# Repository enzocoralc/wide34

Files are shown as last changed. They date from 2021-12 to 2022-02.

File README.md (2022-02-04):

# wide34

⚠️ If you've used the gerbers to fab before 2022/2/4 you'll need to bodge wire the middle TRRS pin (which was connected to P15) to P1 and the inner bottom key side pin (which was connected to P1) to P15.

split 34 keys with 21mm X pitch and chopped chocs for less vertical movement. 
It's promicro compatible and supports only chocs.
Designed in ergogen. You can use this wonderful tool [here](https://ergogen.xyz/). Disclaimer: the ergogen file here does not output the same edgecuts as the final pcb.

Left side

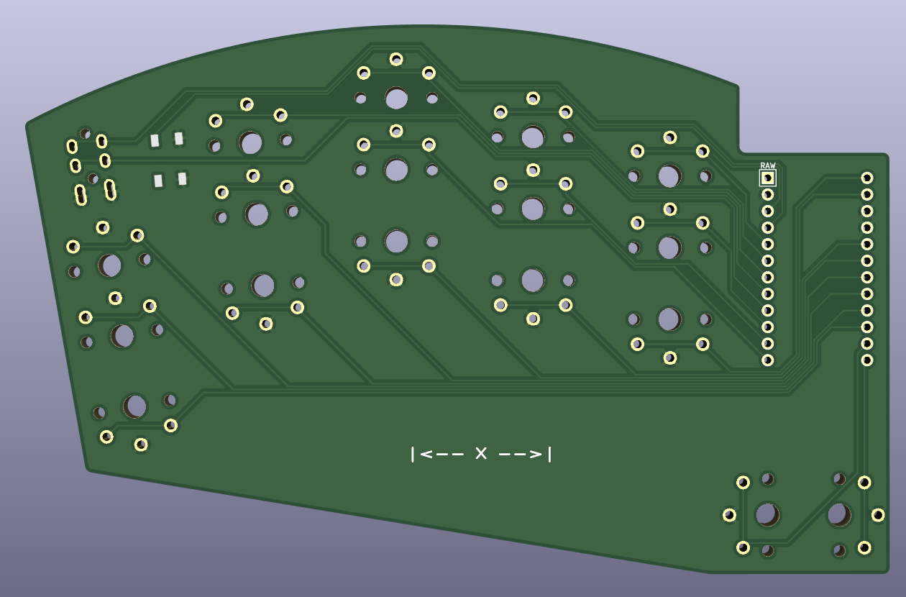
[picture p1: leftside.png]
 
 
 Right side
 
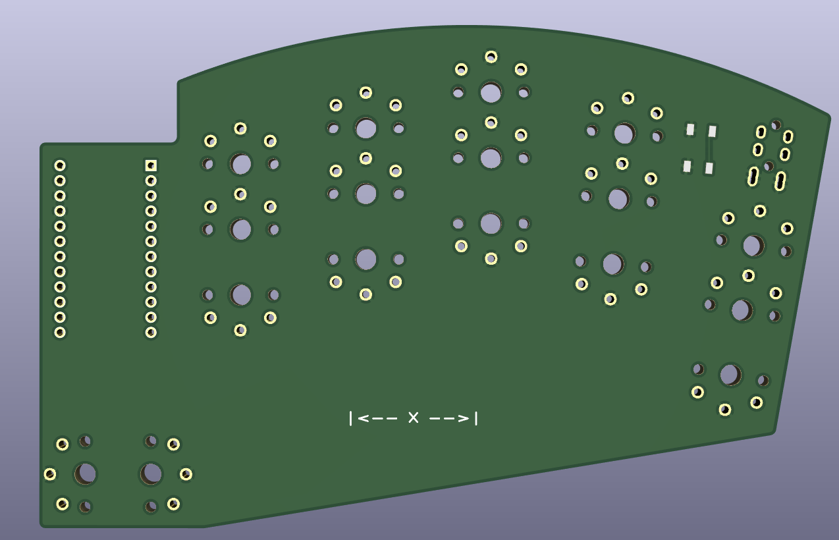
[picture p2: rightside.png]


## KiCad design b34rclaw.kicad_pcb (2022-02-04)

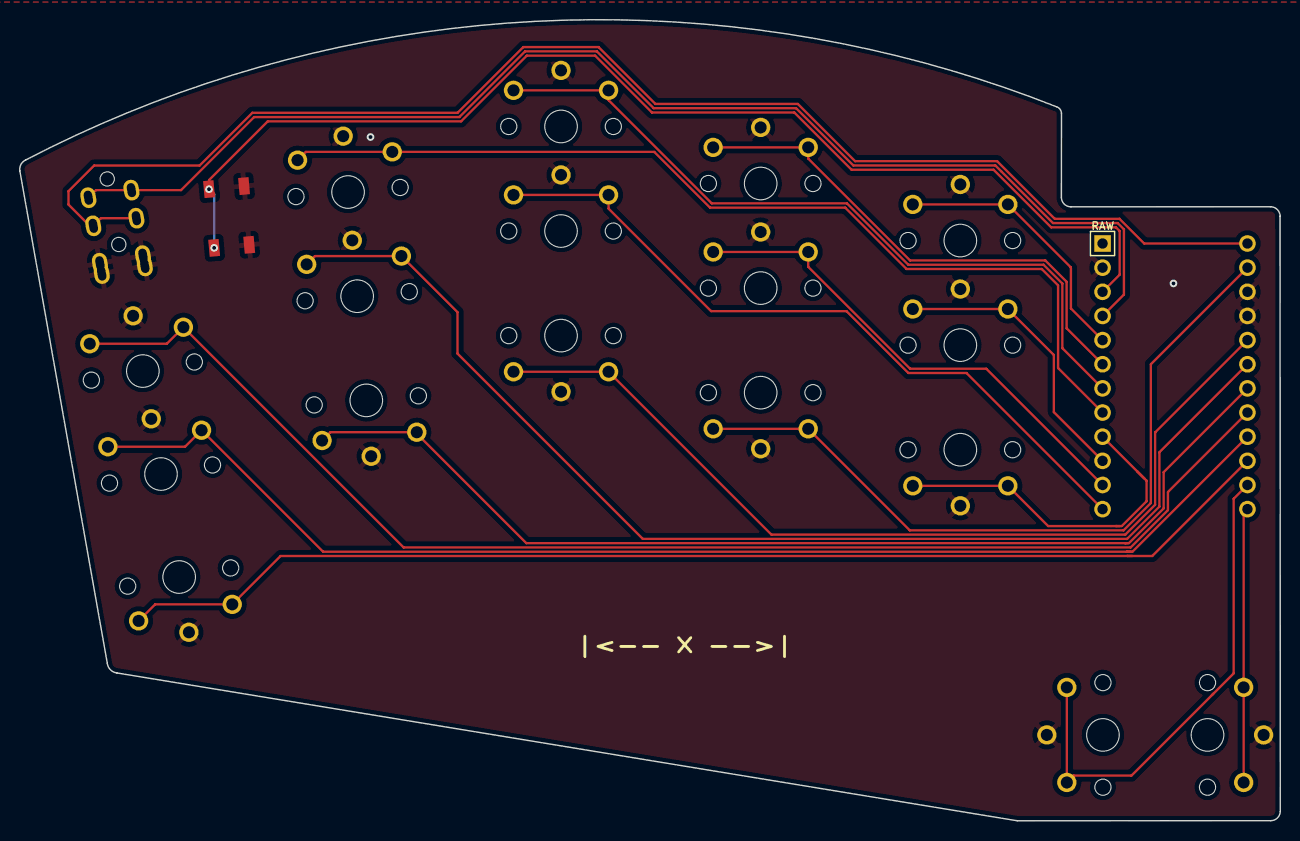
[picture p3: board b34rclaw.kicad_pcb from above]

Board: 2 copper layers, 132.6 x 84.3 mm, 20 parts (0 on the bottom side), 19 nets.

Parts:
B1, B2: SW_TACT_ALPS_SKQGABE010
MCU1: ProMicro
S1, S2, S3, S4, S5, S6, S7, S8, S9, S10, S11, S12, S13, S14, S15, S16, S17: PG1350

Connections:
GND: B1.2, B2.2, MCU1.2, MCU1.15, MCU1.16, S1.2, S2.2, S3.2, S4.2, S5.2, S6.2, S7.2, S8.2, S9.2, S10.2, S11.2, S12.2, S13.2, S14.2, S15.2, S16.2, S17.2
P0: MCU1.14, S10.1
P2: MCU1.17, S7.1
P3: MCU1.18, S5.1
P4: MCU1.19, S4.1
P5: MCU1.20, S3.1
P6: MCU1.21, S2.1
P7: MCU1.22, S1.1
P8: MCU1.23, S16.1
P9: MCU1.24, S17.1
P10: MCU1.12, S8.1
P14: MCU1.10, S14.1
P15: MCU1.9, S13.1
P16: MCU1.11, S11.1
P18: MCU1.8, S6.1
P19: MCU1.7, S9.1
P20: MCU1.6, S12.1
P21: MCU1.5, S15.1
RST: B1.1, B2.1, MCU1.3

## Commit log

2021-12-29 added everything
    [shoggotwide-B_Cu.gbr, shoggotwide-B_Mask.gbr, shoggotwide-B_Paste.gbr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]
2022-02-04 fixed trrs wiring
    [b34rclaw-B_Cu.gbr, b34rclaw-B_Mask.gbr, b34rclaw-B_Paste.gbr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]
2022-02-04 added warning for earlier pcb design
